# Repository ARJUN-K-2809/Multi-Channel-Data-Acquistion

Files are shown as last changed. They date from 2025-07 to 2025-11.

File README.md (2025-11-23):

# ⚡ 8-Channel High-Speed MultiChannel DAQ System (500kSPS)

## 📖 Overview

This project focuses on the development of a **high-speed, multi-channel data acquisition system (DAQ)** capable of sampling **8 differential input channels** at an aggregate rate of **500kSPS**.  

The system is designed for use in **high-speed sensor data acquisition**, **industrial monitoring**, **control systems**, and **real-time signal analysis** where accuracy, low-noise design, and scalability are critical.

This DAQ emphasizes:
- Differential signal integrity  
- Noise immunity  
- Modular expandability  
- Real-time digital data streaming  

---

## 🚀 Key Features

- ✅ **8 Differential Analog Input Channels**  
- ✅ **500kSPS High-Speed ADC System**  
- ✅ Precision Differential Signal Conditioning Front-End  
- ✅ Optimized low-noise PCB layout with analog/digital isolation  
- ✅ SPI Communication Interface for MCU/FPGA systems  
- ✅ Onboard test points for debugging and signal probing  
- ✅ Designed for integration with embedded platforms  
- ✅ Expandable architecture for future scaling  

---

## ⚙️ System Architecture

The system is split into four main functional blocks:

1. **Differential Analog Front-End**  
   - Converts sensor signals into stable, low-noise differential outputs  
   - Protects ADC inputs from overvoltage and noise  

2. **8-Channel High-Speed ADC**  
   - Supports high-precision sampling  
   - Total throughput up to **500,000 samples per second**  
   - Compatible with SPI-based microcontrollers or FPGA systems  

3. **Power Management**  
   - Low-noise LDO regulators for analog and digital supplies  
   - Filtered power domains for improved performance  

4. **Digital Interface Layer**  
   - Standard SPI interface  
   - Optional external clock input  
   - Compatible with STM32, ESP32, and FPGA boards  

---

## 📊 Current Project Status

✅ PCB Designed  
✅ PCB Fabricated  
✅ Components Assembled  
🧪 **Hardware Testing In Progress**  
🧪 Signal Integrity Verification  
🧪 ADC Performance Characterization  
🧪 Noise and Crosstalk Measurements  

The board is currently being tested to validate:
- Sampling stability at 500kSPS  
- Channel-to-channel isolation  
- Differential signal performance  
- Noise floor and dynamic range  

---

## 🖥️ Hardware Specifications

| Feature | Specification |
|---|---|
| Input Channels | 8 Differential |
| Max Sampling Rate | 500kSPS |
| Resolution | Configurable (depends on ADC used) |
| Communication | SPI |
| PCB Layers | 2-Layer |
| Front-End Type | Fully Differential |

---

## 🧪 Testing and Validation

Ongoing hardware testing includes:

- ✔ ADC linearity and INL/DNL testing  
- ✔ High-frequency signal response  
- ✔ Noise spectrum analysis  
- ✔ Crosstalk measurement across channels  
- ✔ Long-term stability analysis  

Preliminary results indicate **stable sampling performance close to the target 500kSPS rate**.

Detailed test results will be added soon in the `/docs` folder.

---

## 🔌 Planned Firmware Features

Firmware development will support:

- Interrupt or DMA-based ADC sampling  
- 8-channel data multiplexing and control  
- Circular buffering for real-time streaming  
- Dynamic sampling configuration  
- USB/UART data streaming to PC  
- Simple command-based interface  

Supported platforms:
- FPGA-based controllers  

---

## 🎯 Applications

This DAQ system is ideal for:

- Vibration analysis  
- Industrial automation  
- Biomedical instrumentation (non-invasive)  
- Lab measurement equipment  
- Embedded data logging  
- Multi-sensor arrays  

---

## 🔮 Future Improvements

- Higher channel count version (16/32 channels)  
- Higher sampling rate variants  
- USB-C interface  
- FPGA-based acquisition engine  
- Onboard signal processing  
- Isolation for industrial use  

---

## 🤝 Contributions & Collaboration

Contributions and testing support are welcome!  
If you’re interested in collaborating on firmware, software, or hardware validation — feel free to open an issue or fork this repository.

---

## 📜 License

This project is released under the **MIT License**.  
You are free to modify, reuse, and distribute with proper credit.

---

## ⭐ Support

If you find this project useful, feel free to star ⭐ this repo and share feedback!

## 📦 Repository Structure

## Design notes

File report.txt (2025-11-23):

Plotted to 'E:\IIT PALAKKAD\SEM V ARCHIVES\OELP\Multi_daq-F_Cu.gbr'.
Plotted to 'E:\IIT PALAKKAD\SEM V ARCHIVES\OELP\Multi_daq-B_Cu.gbr'.
Plotted to 'E:\IIT PALAKKAD\SEM V ARCHIVES\OELP\Multi_daq-F_Paste.gbr'.
Plotted to 'E:\IIT PALAKKAD\SEM V ARCHIVES\OELP\Multi_daq-B_Paste.gbr'.
Plotted to 'E:\IIT PALAKKAD\SEM V ARCHIVES\OELP\Multi_daq-F_Silkscreen.gbr'.
Plotted to 'E:\IIT PALAKKAD\SEM V ARCHIVES\OELP\Multi_daq-B_Silkscreen.gbr'.
Plotted to 'E:\IIT PALAKKAD\SEM V ARCHIVES\OELP\Multi_daq-F_Mask.gbr'.
Plotted to 'E:\IIT PALAKKAD\SEM V ARCHIVES\OELP\Multi_daq-B_Mask.gbr'.
Plotted to 'E:\IIT PALAKKAD\SEM V ARCHIVES\OELP\Multi_daq-Edge_Cuts.gbr'.
Created Gerber job file 'E:\IIT PALAKKAD\SEM V ARCHIVES\OELP\Multi_daq-job.gbrjob'.
Info: Done.
Plotted to 'E:\IIT PALAKKAD\SEM V ARCHIVES\OELP\Multi_daq-F_Cu.gbr'.
Plotted to 'E:\IIT PALAKKAD\SEM V ARCHIVES\OELP\Multi_daq-B_Cu.gbr'.
Plotted to 'E:\IIT PALAKKAD\SEM V ARCHIVES\OELP\Multi_daq-F_Paste.gbr'.
Plotted to 'E:\IIT PALAKKAD\SEM V ARCHIVES\OELP\Multi_daq-B_Paste.gbr'.
Plotted to 'E:\IIT PALAKKAD\SEM V ARCHIVES\OELP\Multi_daq-F_Silkscreen.gbr'.
Plotted to 'E:\IIT PALAKKAD\SEM V ARCHIVES\OELP\Multi_daq-B_Silkscreen.gbr'.
Plotted to 'E:\IIT PALAKKAD\SEM V ARCHIVES\OELP\Multi_daq-F_Mask.gbr'.
Plotted to 'E:\IIT PALAKKAD\SEM V ARCHIVES\OELP\Multi_daq-B_Mask.gbr'.
Plotted to 'E:\IIT PALAKKAD\SEM V ARCHIVES\OELP\Multi_daq-Edge_Cuts.gbr'.
Created Gerber job file 'E:\IIT PALAKKAD\SEM V ARCHIVES\OELP\Multi_daq-job.gbrjob'.
Info: Done.
Plotted to 'E:\KIcad projects\Multi_daq\Multi_daq-F_Cu.gbr'.
Plotted to 'E:\KIcad projects\Multi_daq\Multi_daq-B_Cu.gbr'.
Plotted to 'E:\KIcad projects\Multi_daq\Multi_daq-F_Paste.gbr'.
Plotted to 'E:\KIcad projects\Multi_daq\Multi_daq-B_Paste.gbr'.
Plotted to 'E:\KIcad projects\Multi_daq\Multi_daq-F_Silkscreen.gbr'.
Plotted to 'E:\KIcad projects\Multi_daq\Multi_daq-B_Silkscreen.gbr'.
Plotted to 'E:\KIcad projects\Multi_daq\Multi_daq-F_Mask.gbr'.
Plotted to 'E:\KIcad projects\Multi_daq\Multi_daq-B_Mask.gbr'.
Plotted to 'E:\KIcad projects\Multi_daq\Multi_daq-Edge_Cuts.gbr'.
Created Gerber job file 'E:\KIcad projects\Multi_daq\Multi_daq-job.gbrjob'.
Info: Done.
Info: Done.
Info: Done.
Info: Done.

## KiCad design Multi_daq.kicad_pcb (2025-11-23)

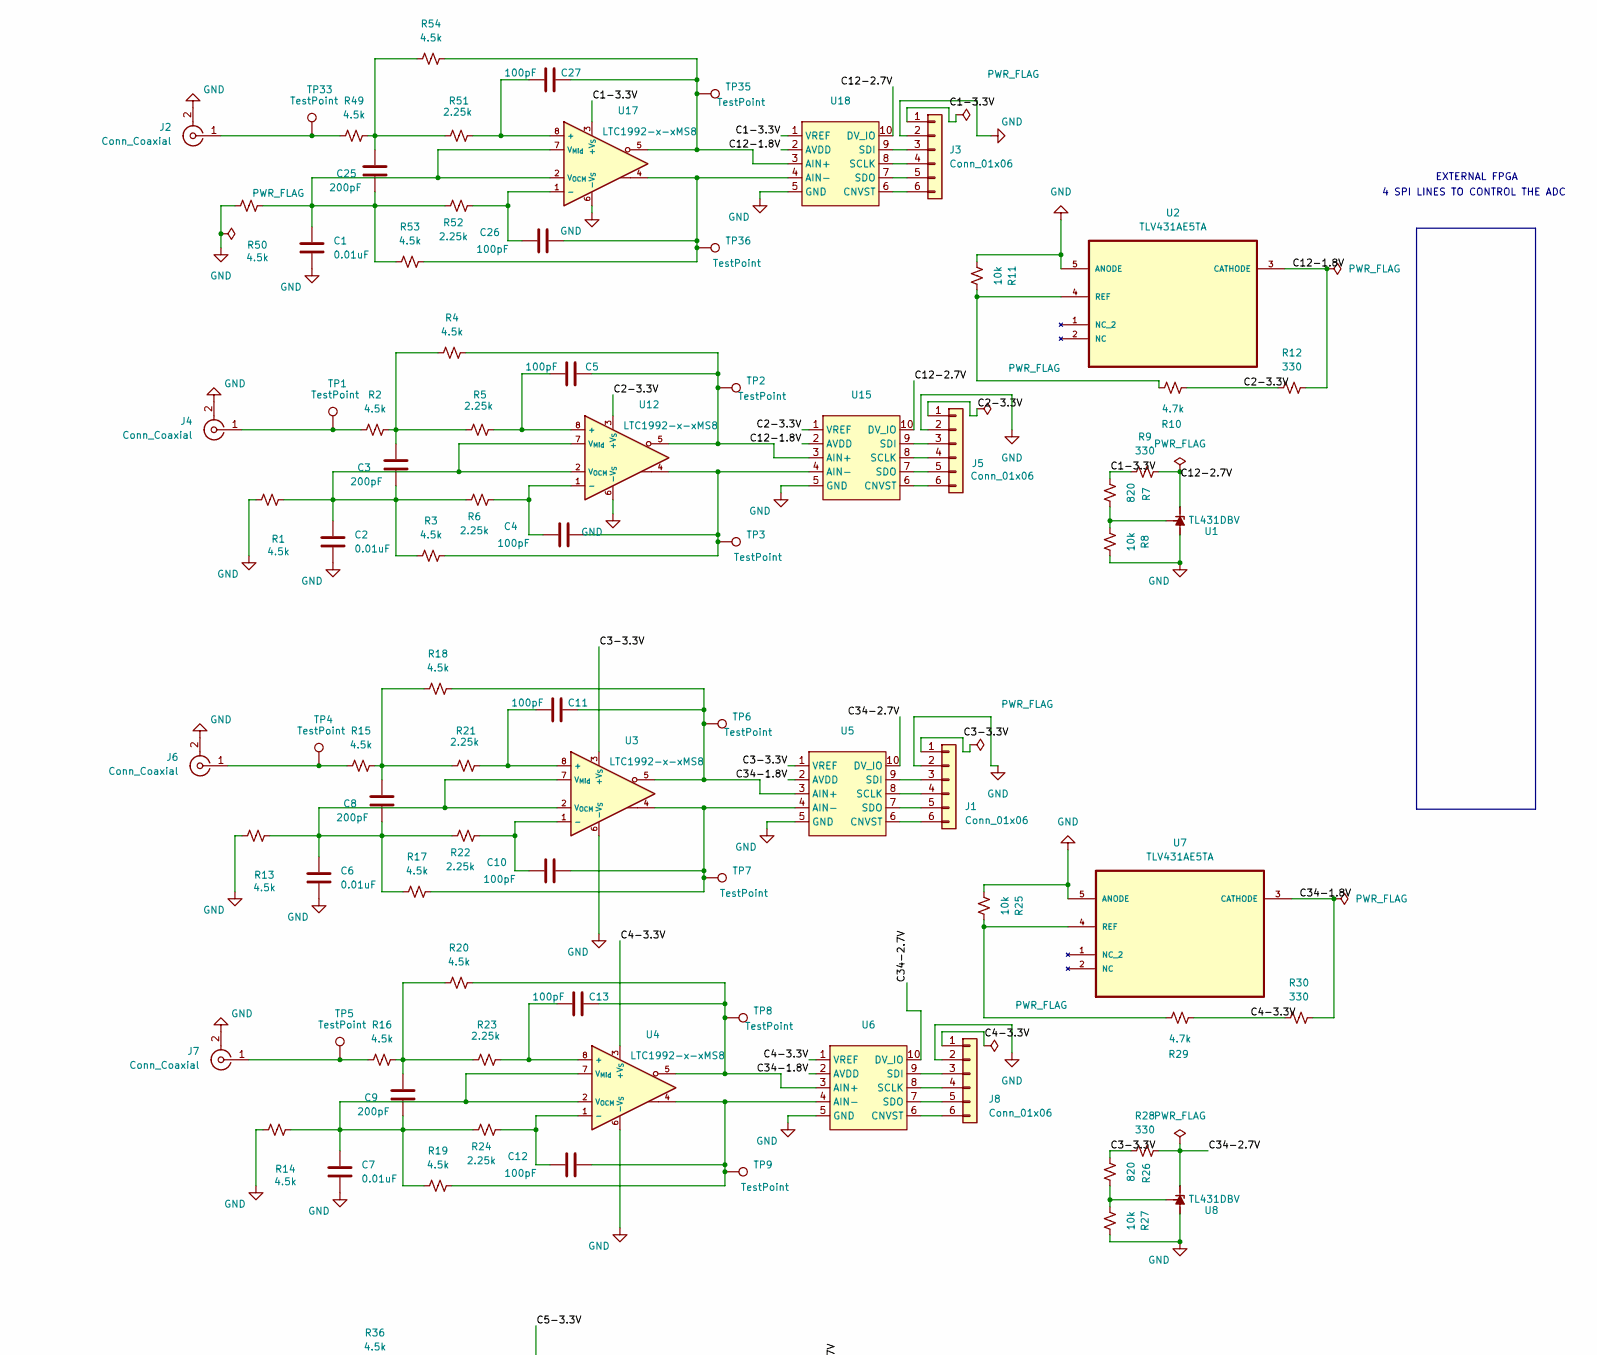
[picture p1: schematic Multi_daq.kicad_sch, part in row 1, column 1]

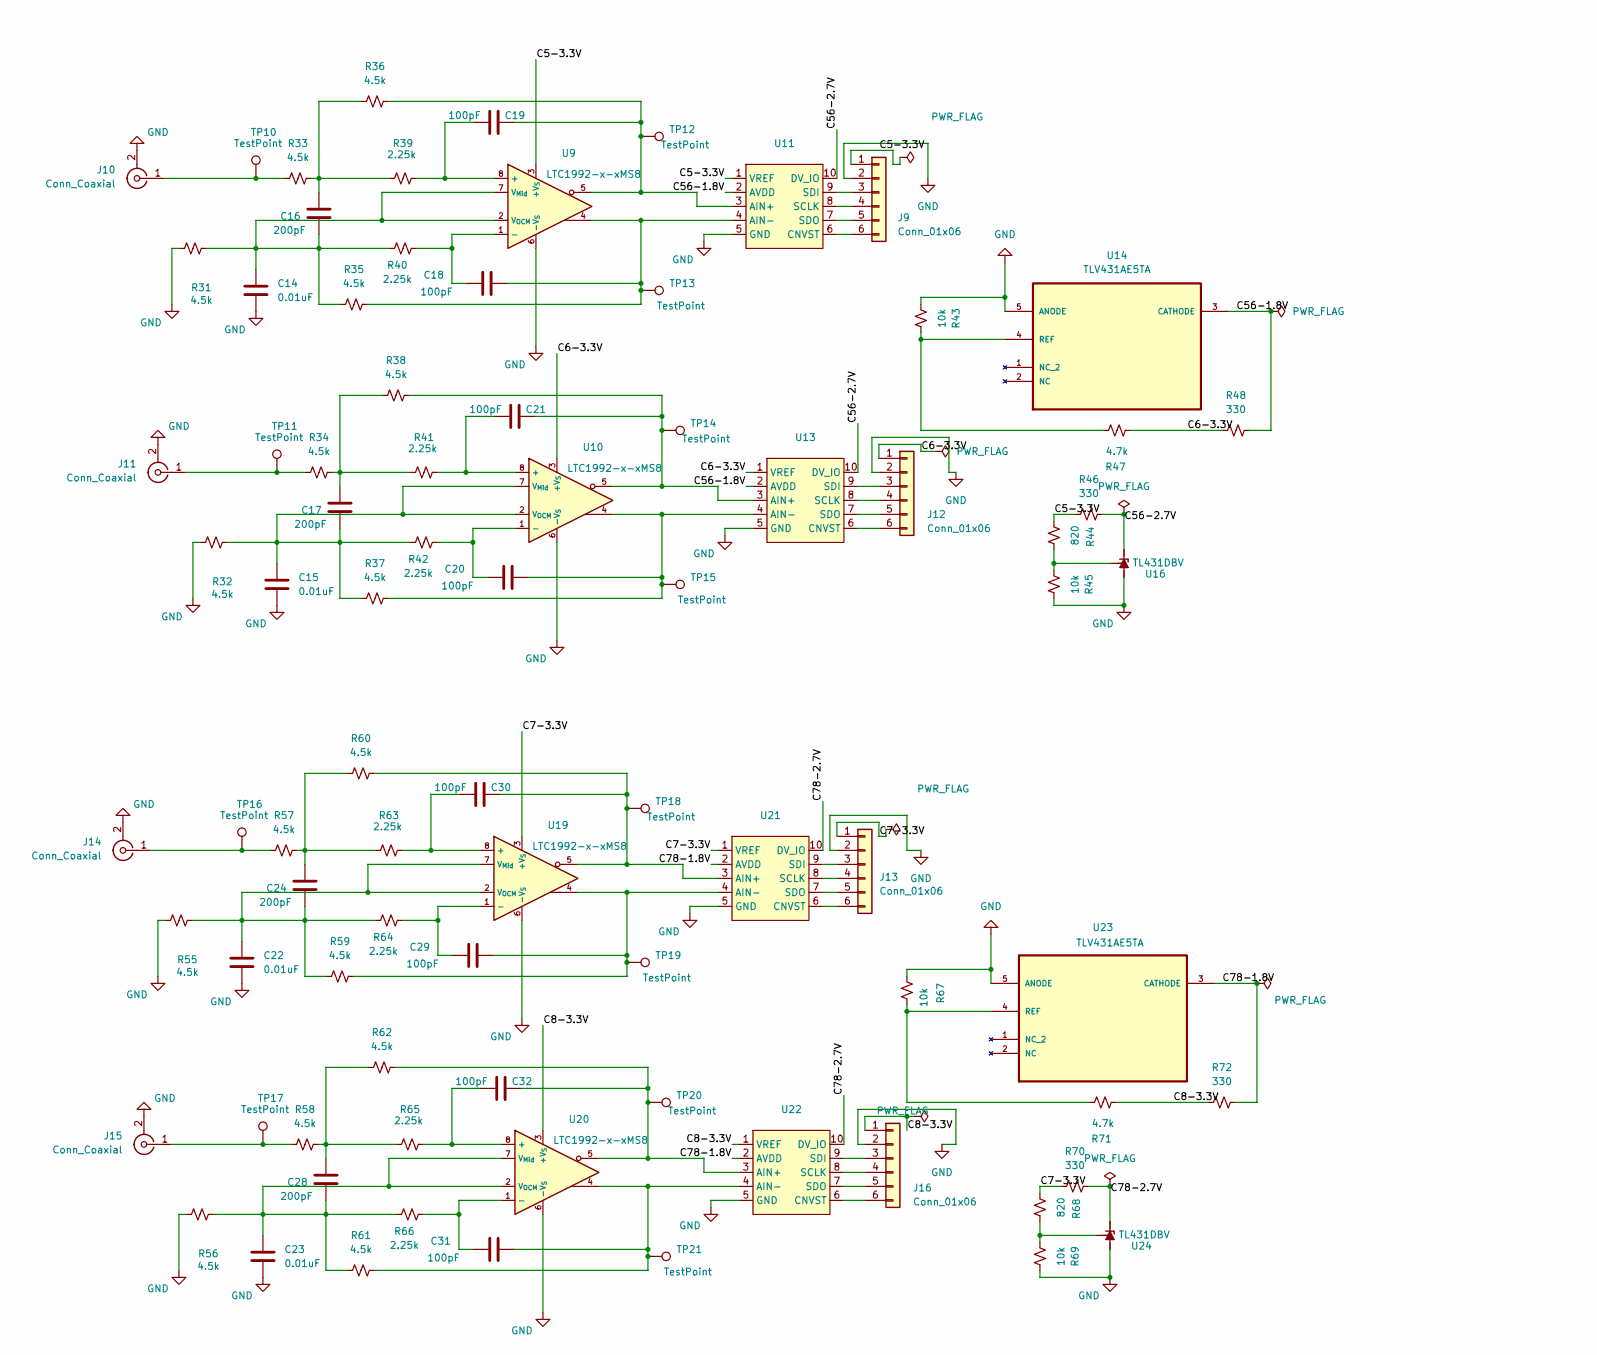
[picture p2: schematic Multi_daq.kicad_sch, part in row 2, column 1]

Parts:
C1, C2, C6, C7, C14, C15, C22, C23: 0.01uF; C_Disc_D5.0mm_W2.5mm_P2.50mm
C3, C8, C9, C16, C17, C24, C25, C28: 200pF; C_Disc_D5.0mm_W2.5mm_P2.50mm
C4, C5, C10, C11, C12, C13, C18, C19, C20, C21, C26, C27, C29, C30, C31, C32: 100pF; C_Disc_D5.0mm_W2.5mm_P2.50mm
J1, J3, J5, J8, J9, J12, J13, J16: Conn_01x06; PinHeader_1x06_P2.54mm_Vertical
J2, J4, J6, J7, J10, J11, J14, J15: Conn_Coaxial; BNC-modified
R1, R2, R3, R4, R13, R14, R15, R16, R17, R18, R19, R20, R31, R32, R33, R34, R35, R36, R37, R38, R49, R50, R53, R54, R55, R56, R57, R58, R59, R60, R61, R62: 4.5k; R_Axial_DIN0207_L6.3mm_D2.5mm_P7.62mm_Horizontal
R5, R6, R21, R22, R23, R24, R39, R40, R41, R42, R51, R52, R63, R64, R65, R66: 2.25k; R_Axial_DIN0207_L6.3mm_D2.5mm_P7.62mm_Horizontal
R7, R26, R44, R68: 820; R_Axial_DIN0207_L6.3mm_D2.5mm_P7.62mm_Horizontal
R8, R11, R25, R27, R43, R45, R67, R69: 10k; R_Axial_DIN0207_L6.3mm_D2.5mm_P7.62mm_Horizontal
R9, R12, R28, R30, R46, R48, R70, R72: 330; R_Axial_DIN0207_L6.3mm_D2.5mm_P7.62mm_Horizontal
R10, R29, R47, R71: 4.7k; R_Axial_DIN0207_L6.3mm_D2.5mm_P7.62mm_Horizontal
TP1, TP2, TP3, TP4, TP5, TP6, TP7, TP8, TP9, TP10, TP11, TP12, TP13, TP14, TP15, TP16, TP17, TP18, TP19, TP20, TP21, TP33, TP35, TP36: TestPoint; TestPoint_Loop_D2.50mm_Drill1.0mm
U1, U8, U16, U24: TL431DBV; SOT-23-5
U2, U7, U14, U23: TLV431AE5TA; MPN TLV431AE5TA
U3, U4, U9, U10, U12, U17, U19, U20: LTC1992-x-xMS8; MSOP-8_3x3mm_P0.65mm
U5, U6, U11, U13, U15, U18, U21, U22: SOP50P490X110-10N

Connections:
/C1-3.3V: J3.1, R7.1, R9.1, U17.3 (+V_{S}), U18.1 (VREF)
/C2-3.3V: J5.1, R10.1, R12.1, U12.3 (+V_{S}), U15.1 (VREF)
/C3-3.3V: J1.1, R26.1, R28.1, U3.3 (+V_{S}), U5.1 (VREF)
/C4-3.3V: J8.1, R29.1, R30.1, U4.3 (+V_{S}), U6.1 (VREF)
/C5-3.3V: J9.1, R44.1, R46.1, U9.3 (+V_{S}), U11.1 (VREF)
/C6-3.3V: J12.1, R47.1, R48.1, U10.3 (+V_{S}), U13.1 (VREF)
/C7-3.3V: J13.1, R68.1, R70.1, U19.3 (+V_{S}), U21.1 (VREF)
/C8-3.3V: J16.1, R71.1, R72.1, U20.3 (+V_{S}), U22.1 (VREF)
/C12-1.8V: R12.2, U2.3 (CATHODE), U15.2 (AVDD), U18.2 (AVDD)
/C12-2.7V: R9.2, U1.3 (K), U15.10 (DV_IO), U18.10 (DV_IO)
/C34-1.8V: R30.2, U5.2 (AVDD), U6.2 (AVDD), U7.3 (CATHODE)
/C34-2.7V: R28.2, U5.10 (DV_IO), U6.10 (DV_IO), U8.3 (K)
/C56-1.8V: R48.2, U11.2 (AVDD), U13.2 (AVDD), U14.3 (CATHODE)
/C56-2.7V: R46.2, U11.10 (DV_IO), U13.10 (DV_IO), U16.3 (K)
/C78-1.8V: R72.2, U21.2 (AVDD), U22.2 (AVDD), U23.3 (CATHODE)
/C78-2.7V: R70.2, U21.10 (DV_IO), U22.10 (DV_IO), U24.3 (K)
GND: C1.2, C2.2, C6.2, C7.2, C14.2, C15.2, C22.2, C23.2, J1.2, J2.2 (Ext), J3.2, J4.2 (Ext), J5.2, J6.2 (Ext), J7.2 (Ext), J8.2, J9.2, J10.2 (Ext), J11.2 (Ext), J12.2, J13.2, J14.2 (Ext), J15.2 (Ext), J16.2, R1.1, R8.1, R11.2, R13.1, R14.1, R25.2, R27.1, R31.1, R32.1, R43.2, R45.1, R50.1, R55.1, R56.1, R67.2, R69.1, U1.5 (A), U2.5 (ANODE), U3.6 (-V_{S}), U4.6 (-V_{S}), U5.5 (GND), U6.5 (GND), U7.5 (ANODE), U8.5 (A), U9.6 (-V_{S}), U10.6 (-V_{S}), U11.5 (GND), U12.6 (-V_{S}), U13.5 (GND), U14.5 (ANODE), U15.5 (GND), U16.5 (A), U17.6 (-V_{S}), U18.5 (GND), U19.6 (-V_{S}), U20.6 (-V_{S}), U21.5 (GND), U22.5 (GND), U23.5 (ANODE), U24.5 (A)
unnamed: C3.2, R2.2, R4.1, R5.1
unnamed: C8.2, R15.2, R18.1, R21.1
unnamed: C9.2, R16.2, R20.1, R23.1
unnamed: C16.2, R33.2, R36.1, R39.1
unnamed: C17.2, R34.2, R38.1, R41.1
unnamed: C24.2, R57.2, R60.1, R63.1
unnamed: C25.2, R49.2, R51.1, R54.1
unnamed: C28.2, R58.2, R62.1, R65.1
unnamed: J1.3, U5.9 (SDI)
unnamed: J1.4, U5.8 (SCLK)
unnamed: J1.5, U5.7 (SDO)
unnamed: J1.6, U5.6 (CNVST)
unnamed: J2.1 (In), R49.1, TP33.1
unnamed: J3.3, U18.9 (SDI)
unnamed: J3.4, U18.8 (SCLK)
unnamed: J3.5, U18.7 (SDO)
unnamed: J3.6, U18.6 (CNVST)
unnamed: J4.1 (In), R2.1, TP1.1
unnamed: J5.3, U15.9 (SDI)
unnamed: J5.4, U15.8 (SCLK)
unnamed: J5.5, U15.7 (SDO)
unnamed: J5.6, U15.6 (CNVST)
unnamed: J6.1 (In), R15.1, TP4.1
unnamed: J7.1 (In), R16.1, TP5.1
unnamed: J8.3, U6.9 (SDI)
unnamed: J8.4, U6.8 (SCLK)
unnamed: J8.5, U6.7 (SDO)
unnamed: J8.6, U6.6 (CNVST)
unnamed: J9.3, U11.9 (SDI)
unnamed: J9.4, U11.8 (SCLK)
unnamed: J9.5, U11.7 (SDO)
unnamed: J9.6, U11.6 (CNVST)
unnamed: J10.1 (In), R33.1, TP10.1
unnamed: J11.1 (In), R34.1, TP11.1
unnamed: J12.3, U13.9 (SDI)
unnamed: J12.4, U13.8 (SCLK)
unnamed: J12.5, U13.7 (SDO)
unnamed: J12.6, U13.6 (CNVST)
unnamed: J13.3, U21.9 (SDI)
unnamed: J13.4, U21.8 (SCLK)
unnamed: J13.5, U21.7 (SDO)
unnamed: J13.6, U21.6 (CNVST)
unnamed: J14.1 (In), R57.1, TP16.1
unnamed: J15.1 (In), R58.1, TP17.1
unnamed: J16.3, U22.9 (SDI)
unnamed: J16.4, U22.8 (SCLK)
unnamed: J16.5, U22.7 (SDO)
unnamed: J16.6, U22.6 (CNVST)
unnamed: R7.2, R8.2, U1.4 (REF)
unnamed: R10.2, R11.1, U2.4 (REF)
unnamed: C11.1, R21.2, U3.8 (+)
unnamed: C10.1, R22.2, U3.1 (-)
unnamed: C6.1, C8.1, R13.2, R17.1, R22.1, U3.2 (V_{OCM}), U3.7 (V_{Mid})
unnamed: C13.1, R23.2, U4.8 (+)
unnamed: C12.1, R24.2, U4.1 (-)
unnamed: C7.1, C9.1, R14.2, R19.1, R24.1, U4.2 (V_{OCM}), U4.7 (V_{Mid})
unnamed: C11.2, R18.2, TP6.1, U3.5, U5.3 (AIN+)
unnamed: C10.2, R17.2, TP7.1, U3.4, U5.4 (AIN-)
unnamed: C13.2, R20.2, TP8.1, U4.5, U6.3 (AIN+)
unnamed: C12.2, R19.2, TP9.1, U4.4, U6.4 (AIN-)
unnamed: R25.1, R29.2, U7.4 (REF)
unnamed: R26.2, R27.2, U8.4 (REF)
unnamed: C19.1, R39.2, U9.8 (+)
unnamed: C18.1, R40.2, U9.1 (-)
unnamed: C14.1, C16.1, R31.2, R35.1, R40.1, U9.2 (V_{OCM}), U9.7 (V_{Mid})
unnamed: C21.1, R41.2, U10.8 (+)
unnamed: C20.1, R42.2, U10.1 (-)
unnamed: C15.1, C17.1, R32.2, R37.1, R42.1, U10.2 (V_{OCM}), U10.7 (V_{Mid})
unnamed: C19.2, R36.2, TP12.1, U9.5, U11.3 (AIN+)
unnamed: C18.2, R35.2, TP13.1, U9.4, U11.4 (AIN-)
unnamed: C5.1, R5.2, U12.8 (+)
unnamed: C4.1, R6.2, U12.1 (-)
unnamed: C2.1, C3.1, R1.2, R3.1, R6.1, U12.2 (V_{OCM}), U12.7 (V_{Mid})
unnamed: C21.2, R38.2, TP14.1, U10.5, U13.3 (AIN+)
unnamed: C20.2, R37.2, TP15.1, U10.4, U13.4 (AIN-)
unnamed: R43.1, R47.2, U14.4 (REF)
unnamed: C5.2, R4.2, TP2.1, U12.5, U15.3 (AIN+)
unnamed: C4.2, R3.2, TP3.1, U12.4, U15.4 (AIN-)
unnamed: R44.2, R45.2, U16.4 (REF)
unnamed: C27.1, R51.2, U17.8 (+)
unnamed: C26.1, R52.2, U17.1 (-)
unnamed: C1.1, C25.1, R50.2, R52.1, R53.1, U17.2 (V_{OCM}), U17.7 (V_{Mid})
unnamed: C27.2, R54.2, TP35.1, U17.5, U18.3 (AIN+)
unnamed: C26.2, R53.2, TP36.1, U17.4, U18.4 (AIN-)
unnamed: C30.1, R63.2, U19.8 (+)
unnamed: C29.1, R64.2, U19.1 (-)
unnamed: C22.1, C24.1, R55.2, R59.1, R64.1, U19.2 (V_{OCM}), U19.7 (V_{Mid})
unnamed: C32.1, R65.2, U20.8 (+)
unnamed: C31.1, R66.2, U20.1 (-)
unnamed: C23.1, C28.1, R56.2, R61.1, R66.1, U20.2 (V_{OCM}), U20.7 (V_{Mid})
unnamed: C30.2, R60.2, TP18.1, U19.5, U21.3 (AIN+)
unnamed: C29.2, R59.2, TP19.1, U19.4, U21.4 (AIN-)
unnamed: C32.2, R62.2, TP20.1, U20.5, U22.3 (AIN+)
unnamed: C31.2, R61.2, TP21.1, U20.4, U22.4 (AIN-)
unnamed: R67.1, R71.2, U23.4 (REF)
unnamed: R68.2, R69.2, U24.4 (REF)

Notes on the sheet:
EXTERNAL FPGA
4 SPI LINES TO CONTROL THE ADC

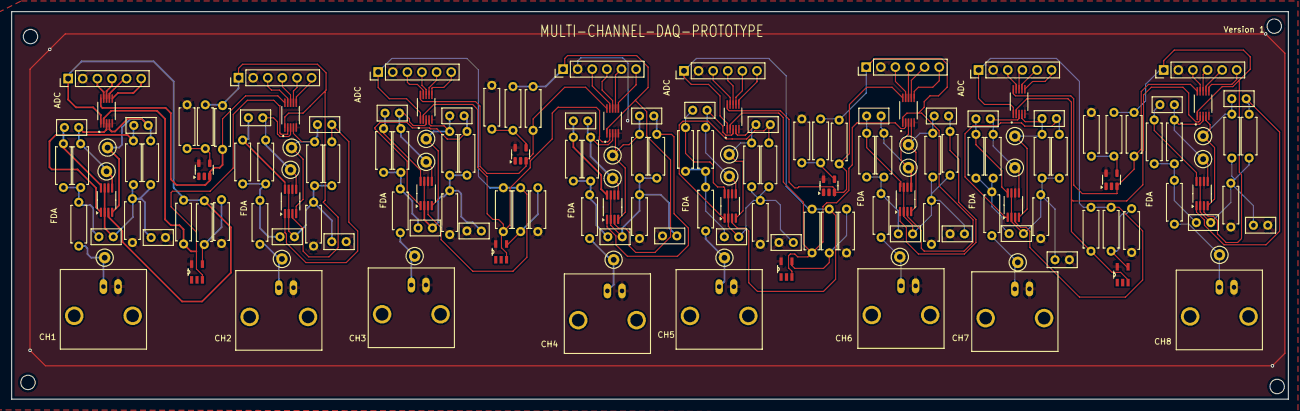
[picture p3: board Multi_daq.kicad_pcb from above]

Board: 2 copper layers, 222.0 x 67.4 mm, 168 parts (0 on the bottom side), 113 nets.

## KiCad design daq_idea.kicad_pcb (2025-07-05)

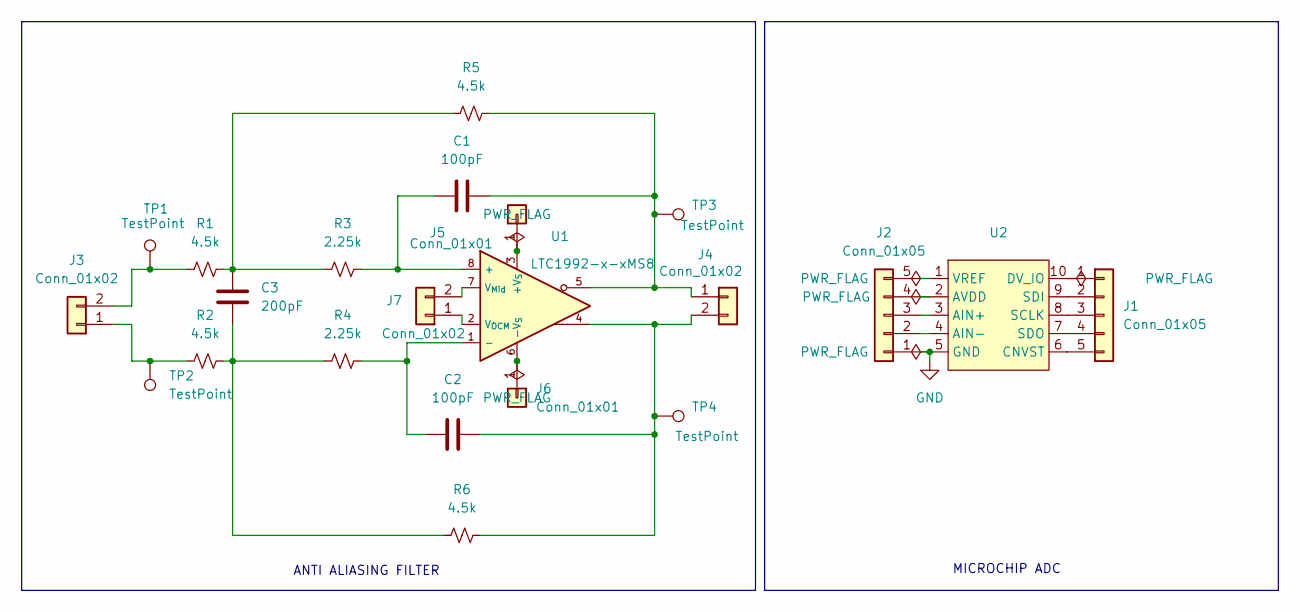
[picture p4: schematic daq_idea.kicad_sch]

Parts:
C1, C2: 100pF; C_Disc_D5.0mm_W2.5mm_P2.50mm
C3: 200pF; C_Disc_D5.0mm_W2.5mm_P2.50mm
J1, J2: Conn_01x05; PinHeader_1x05_P2.54mm_Vertical
J3, J4, J7: Conn_01x02; PinHeader_1x02_P2.54mm_Vertical
J5, J6: Conn_01x01; PinHeader_1x01_P1.00mm_Vertical
R1, R2, R5, R6: 4.5k; R_Axial_DIN0207_L6.3mm_D2.5mm_P7.62mm_Horizontal
R3, R4: 2.25k; R_Axial_DIN0207_L6.3mm_D2.5mm_P7.62mm_Horizontal
TP1, TP2, TP3, TP4: TestPoint; TestPoint_Loop_D2.50mm_Drill1.0mm
U1: LTC1992-x-xMS8; MSOP-8_3x3mm_P0.65mm
U2: SOP50P490X110-10N

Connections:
GND: J2.1, U2.5 (GND)
unnamed: C3.1, R2.2, R4.1, R6.1
unnamed: C3.2, R1.2, R3.1, R5.1
unnamed: J1.1, U2.10 (DV_IO)
unnamed: J1.2, U2.9 (SDI)
unnamed: J1.3, U2.8 (SCLK)
unnamed: J1.4, U2.7 (SDO)
unnamed: J1.5, U2.6 (CNVST)
unnamed: J2.2, U2.4 (AIN-)
unnamed: J2.3, U2.3 (AIN+)
unnamed: J2.4, U2.2 (AVDD)
unnamed: J2.5, U2.1 (VREF)
unnamed: J3.1, R2.1, TP2.1
unnamed: J3.2, R1.1, TP1.1
unnamed: C1.2, J4.1, R5.2, TP3.1, U1.5
unnamed: C2.2, J4.2, R6.2, TP4.1, U1.4
unnamed: J5.1, U1.3 (+V_{S})
unnamed: J6.1, U1.6 (-V_{S})
unnamed: J7.1, U1.2 (V_{OCM})
unnamed: J7.2, U1.7 (V_{Mid})
unnamed: C1.1, R3.2, U1.8 (+)
unnamed: C2.1, R4.2, U1.1 (-)

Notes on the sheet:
ANTI ALIASING FILTER
MICROCHIP ADC

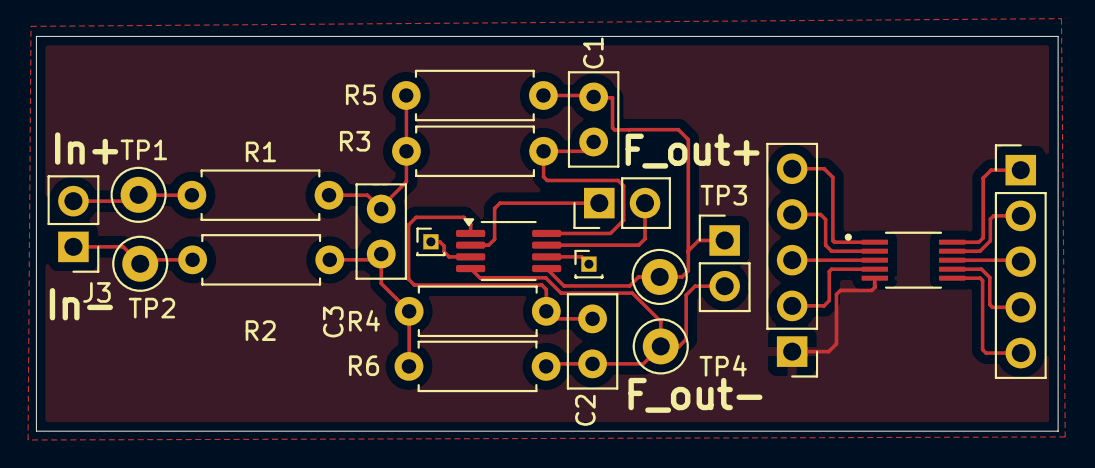
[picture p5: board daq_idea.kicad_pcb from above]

Board: 2 copper layers, 56.8 x 21.9 mm, 22 parts (0 on the bottom side), 22 nets.
